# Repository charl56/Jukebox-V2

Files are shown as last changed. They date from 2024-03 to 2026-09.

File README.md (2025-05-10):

# Jukebox

This project combines **hardware** and **software** to create a connected jukebox.
It runs on a **Raspberry Pi 3B**, which hosts a web server you can access to control music playback.
The hardware part manages various components directly connected to the Pi for full jukebox functionality.

---

## Web technologies Used

* **Python**: 3.11.1
* **Node.js**: 16.17.0

---

## Run Locally

### 1. Frontend Setup

1. Navigate to the `frontend` folder:

   ```bash
   cd frontend
   ```
2. Install dependencies (only needed the first time or after adding new ones):

   ```bash
   npm install
   ```
3. Start the development server:

   ```bash
   npm run dev
   ```

---

### 2. Backend Setup

1. Navigate to the `backend` folder:

   ```bash
   cd backend
   ```
2. Install Python dependencies:

   ```bash
   pip install -r requirements.txt
   ```
3. Run the app:

   ```bash
   python app.py
   ```

* **Access the app at**: [http://127.0.0.1:8080](http://127.0.0.1:8080)

---

## Raspberry Pi Setup

Full instructions are available here:
📄 [Step-by-step guide](./raspberry/README.MD)

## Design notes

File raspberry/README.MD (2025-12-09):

# Raspberry Pi Documentation

This guide is based for a **Raspberry Pi 3B**.

## 1. Software Setup

Start with the software setup:
📄 [Step-by-step guide](./0_software/0_initialisation_raspberry.md)

---

## 2. Hardware Setup

Then follow the hardware installation steps:
📄 [Step-by-step guide](./1_hardware/0_components_position.md)

---

## 3. Useful Commands

If needed, here’s a list of useful commands:
📄 [Command reference](./commands.md)

---

pipeline, 3 jobs :  deploy and build for private and public image of project
    Public is for deploy app on server, for testing
    Private is for Raspberry application

Create `raspberry` branch, to start build and deploy public image for raspberry

Prévoir copier le répertoire git pour récupérer les fichier dans le dossier Raspberry ???

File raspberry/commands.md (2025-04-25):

## Useful commands

```bash
poweroff    # Properly shut down the Raspberry Pi

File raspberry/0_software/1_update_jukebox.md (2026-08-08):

# How to Update the Application

1. **Edit Wi-Fi Settings**
   Open the file `/etc/wpa_supplicant/wpa_supplicant.conf` and update the `ssid` and `psk` with your Wi-Fi credentials.

2. **Switch to Client Mode**
   Run the following command to switch to Wi-Fi client mode:

   ```bash
   sudo ./wifi-ap-switch.sh client
   ```

   Wait a few moments for the Raspberry Pi to connect to the network.

3. **Check Connection**
   Verify the connection with:

   ```bash
   ping ostudio426.com
   ```

4. **Pull the Latest Jukebox Version**
   Run the update script:

   ```bash
   ./pull-jukebox.sh
   ```

   > If an error occurs, simply run the command again.

5. **Reboot the Raspberry Pi**

   ```bash
   sudo reboot
   ```

6. **Start new version**
   Run the start script: 
   ```
   ./start-jukebox.sh
   ```

Then, go to [http://raspberrypi.local](http://raspberrypi.local)
---

## Additional Info

* ⚠️ Sometimes this command may not work properly. In that case, it's better to reboot:

  ```bash
  sudo reboot
  ```

  > The Raspberry Pi will start in AP mode by default.

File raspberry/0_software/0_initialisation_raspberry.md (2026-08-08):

# Raspberry Pi – USB Key Setup (Raspberry Pi OS Lite 64-bit)

## Boot from USB Key with Raspberry Pi OS Lite (64-bit)

Start by install the OS using the image in the `XXX` folder on your SD card.

> The image includes:
>
> * Docker pre-installed
> * Access Point (AP) and Client mode setup
> * Scripts to pull and run the latest Docker image

* **Username:** `user`
* **Password:** `network!`

Une fois connecté vous avez accès à différents script .sh, et également à des fichiers .py pour tester manuellement les composants

🟢 On first boot, the Raspberry starts in Access Point (AP) mode.
You can directly access the Jukebox application already installed.

You need to connect to wifi network `Jukebox`, with SSID : `12345678`

Then, go to [http://raspberrypi.local](http://raspberrypi.local)

---

## Doc : Update Jukebox's application

If you need to update the application:
📄 [Step-by-step guide](./1_update_jukebox.md)

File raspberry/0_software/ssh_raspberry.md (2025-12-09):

# Connexion à la Raspberry Pi et lancement de l'appli

## Première connexion

1. Brancher la carte SD à l'ordinateur.
2. Modifier le fichier `root/cmdline.txt`.
3. Ajouter à la fin du fichier : `ip=169.254.25.25`

## Connexion SSH

1. Brancher la Raspberry Pi au PC via un câble Ethernet.
2. Exécuter la commande SSH suivante :
```bash
ssh -L 5025:127.0.0.1:5025 charl@169.254.25.25
```
3. Mot de passe : `network!`

## Création d'un tunnel avec MobaXterm

1. Ouvrir MobaXterm.
2. Accéder au menu : `Tunneling`.
3. Configurer les options suivantes :

   - **Forwarded port** : `5025`

   * SSH Server :
     - **Adresse** : `169.254.25.25`
     - **User** : `charl`
     - **Port** : `22`

   * Remote Server :
     - **Adresse** : `127.0.0.1`
     - **Port** : `5025`

---
Avec ce setup, vous recevrez le port 5025 de la Raspberry Pi sur votre PC.

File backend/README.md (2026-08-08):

Des fichiers de tests sont sur la raspbrery
pour les lancer : sudo python ...

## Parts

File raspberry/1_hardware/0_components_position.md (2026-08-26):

Pins are setup in 📄 [config file](../../backend/embedded/config.py)

Raspberry PI 3B Model V1.2, pin out
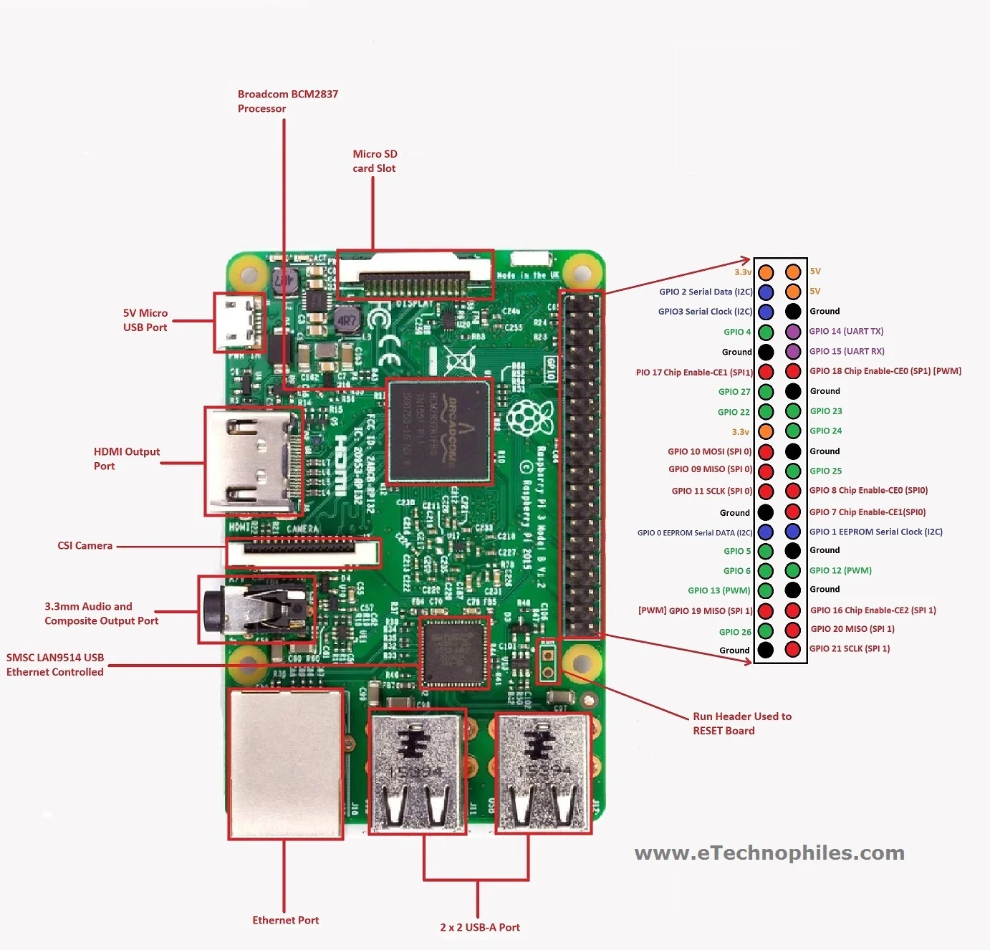
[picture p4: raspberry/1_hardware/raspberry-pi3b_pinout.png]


From : https://www.etechnophiles.com/raspberry-pi-3-gpio-pinout-pin-diagram-and-specs-in-detail-model-b/

Mon fin de course en SWITCH3 étant cassé, je l'utilise à l'envers. Fonction utilisé pour inverser sa valeur 
getRealValueOfSwitch3 dans utils.py

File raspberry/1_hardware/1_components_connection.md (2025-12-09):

Ici, decrire avec des photos/schemas comment brancher les différents composants : moteurs, capteurs, lecteur...

	Contrôler 2 moteurs pas à pas pour déplacement X et Y
		Avec des ponts en H
	Contrôler 1 servo moteur pour déplacement Z
	Contrôler l'activation de l'electro aimant
	Contrôler 4 capteur de fin de course
	Contrôler 3 GPIO en plus : contrôler le lecteur cd
		Play, pause, et pour le capteur qui détecte si le couvercle du lecteur est fermé
	Puissance de processeur/ram pour faire tourner un serveur web, et y accéder en wifi

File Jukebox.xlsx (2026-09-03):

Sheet: Reprise
Jukebox : se poser avec feuille et réfléchir sur le lecteur, prévoir taff dans les prochains jours, dessin du rendu final, s'aider de ce qui existe
Détailler chaques étapes et ordre avant de commencer
 |  | Filmer les anvancées avec les pièces 3D
Tâches | Détail | Avancée | Etapes Construction |  | Etapes Modé 3D |  | Etapes programmation |  | Pièces 3D
Ranger le bureau pour avoir de l'espace pour taffer
Relancer pour voir ce que ça donne
 |  |  | Etapes | Status | Pièce | Status | Etapes | Status | Status | Pièce globale | Pièce 3D | Précision | Dimensions2 | Colonne5 | Colonne1
Mouvements structure |  | 89.00% | Tester accroche CD | Ok | A chaque fois tester les dimensions avant les pièces entières |  | Déplacement X Y manuel | Ok | STL Prêt | Prise CD | Pièce dos cd avec aimant
Trouver 2 capteurs fin de course |  | 100.00% | Tester prise CD avec electro aimant | Ok | Fixer elecamant sur déplacement Z | Ok | Déplacement Z manuel | Ok |  |  |  | Largeur tube dans cd | 1,48cm pour une largeur de 1,5cm
Placements : | - En bas, s'aider de la plaque pour bloquer la descente, sur la droite - En haut, coller le capteur plus bas, sur le raill. - A droite, OK -A gauche, fixer comme droite | 100.00% | Tester déplacement elec aimant Z | Ok | Fixer déplacementZ sur armature imprimante | Pièce OK mais tester deplacement. REFAIRE ?? | Contrôle électro aimant | Ok |  |  |  | Largeur tige qui va dans le plateau du lecteur | 0,57cm pour une largeur de 0,6cm
On mets au max, la positon des cds se fera via config manuelle | Utiliser de la colle ? FAIRE des rallonges | 100.00% | Tester déplacement X et Y | Nickel ! | Pièce sur CD | Ok |  |  |  |  |  | Chanfrein pour épouser la forme du plateau | 1,8cm pour une largent de 1,8cm
Récupérer le signal de la raspberry sur le container docker |  | 100.00%
Regarder lesquels sont branchés où dans le code |  | 100.00% | Installer lecteur CD |  | Support cd avec plaque metal, faire un bout qui depasse, pour centrer le cd | Ok | Lien Docker Pins | Ok |  |  | Pièce face cd avec rondelle
Vérifier potentiomètres moteurs, calcul à la main !! Sans IA au début, puis on vérifie Pb : Moteur X fait du bruit quand branché, CHAAUUFFFEEE | A4988 -> Je ne trouve pas RSens, donc galère de calculer Vref Si pas trop de bruits ~ Okk | 0.00% | Plaque avec support Cds et lecteur, prévoir place lecteur ! | Ok
Vérifier le code pour pour tester manuellement - Fonction moveX/Y, ajouter le recul si capteur detecté |  | 100.00% | Ralonge câbles | Ok | Modéliser rendu final, pour voir où placer quoi | Ok | Pb lecteur, le changer ?? | A faire
Teste manuel déplacement : # Detection des capteurs avec retour marge OK # Fonction moveTo/origin/end OK # Init machine a etats puis attente actions OK # Calibrer les positions OK # playCd -> Bouge au CD puis reviens origin OK // Pb : timeout de 10s, si mouvement plus long la connexion coupe https://claude.ai/chat/1f9255f3-cb82-455e-8c4a-e6fc560f6c47 MIS EN PLACE 30s : TESTER |  | 100.00% | Prévoir tiges? pour fixer armature à planche, avec une certaine distance | Ok |  |  | PREVOIR DES DETECTEURS DE FIN DE COURSE | A faire
# Déplacement Z GOOD MAIS Il faut 3 plaques plutot que des rond en alu pour aimanter les cd sur la face |  | 90.00% |  |  | IMPRIMER PIECES | Ok | Construire stucture | A faire | Prêt, j'ai déjà la pièce | Support pose cd sur mur |  |  |  |  |  | Font
Ajouter le lecteur sur le front avec cd qui tourne + borderau en quand on ferme le lecteur - Voir dessin |  | 100.00% |  |  |  |  | Calculer nb step pour chaque positions | A faire |  |  | Utiliser les plateaux de lecteurs aimantés |  |  |  |  | Tous les cd se refresh quand on dragNdrop
BIEN PLACER STEP MOTEUR POUR STEP 0 TOUT EN HAUT (ORIGINE) |  |  | Construire machine | Ok |  |  | Code général : machine à état | Une fois que tout fonctionne manuellement
MoveX(Dir,Step), on break si on touche un mur, on renvoi quoi dcp ? Ces données ? Non j'imagine, mais dcp on renvoi les qqlq pas du retour ?
Lecteur CD |  | 0.00% |  |  |  |  |  |  | AliExpress | Déplacement elec aimant
Nouveau lecteur à trouver | Trouver ouverture par le dessus, avec une tige de lecteur assez grande | 0.00% |  |  |  |  |  |  |  |  |  |  |  |  |  | Créer image déjà prête, sans imager toute la carte SD. MàJ doc raspberry/0_software/0_initialisation_raspberry.md
 | Avec 4 fixation comme celui actuel | 0.00% |  |  |  |  |  |  |  |  |  |  |  |  |  | "... the image in XXX filder ..."
Tester lecture CD |  | 0.00%
Changer le support | Partie délicate | 0.00%
Sortir le lecteur, check les branchements | J'espère j'ai les mêmes | 0.00%
Remplacer sur la jukebox |  | 0.00% |  |  |  |  | CR2ER IMAGE DE LA CARTE SD DE LA RASPBERRY
 |  |  |  |  |  |  | V2RIFIER README
Machine à états |  | 75.00%
Wait | Attente d'instructions | 100.00%
MoveCdFromTo (X/Y, Z, aimant, Z, X/Y, Z, aimant, Z) | Déplace un CD d'une position à une autre | 100.00%
GoToOrigin | Va à l'origine jusqu'à déclencher les pas à pas | 100.00%
Play/pause/stop | Pour ces actions, liste d'attente ? Ou alors on accepte une nouvelle opération dès que celle en cours est terminée | 0.00%
PCB avec raspberry, driver moteurs, alims...
1 alim pour moteurs, raspberry, lecteur
fichier update_jukebox : faire tous les scritp en 1 ?
Dernière vérif avec multimetre pour valider les moteurs PàP
Déplacement en Z elecAimant
Réimprimer ?? Trouver une imprimante
Application, afficher les CD enregistés : fomarter la hauteur de l'image et largeur pareil pour tout. Ex : ADC et PBB
Image du projet sur la Raspberry
Vidéo présentation
Camera film machine et ecran, l'un a cote de l'autre, les enceintes de chaque côté de la jukebox
On démarre, on va sur le site
On lance un premier CD
Play/pause/volume/suivant...
On change le CD ,on le lance
AJouter/modifier/supprimer dans les CD enregistrés
On change des CDs sur l'interface
On changer également un cd de la jukebox, changement support
Lancement nouveau CD

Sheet: Matos
Moteur 17HS15-0404S | Pilote A4988
Raspberry PI 3B

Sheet: Archive - Setup Raspberry
 |  | Steps | command
 |  | Setup raspOs lite | Raspberry Pi imager
 |  | Install pip3 | apt install python3-pip
 |  | Copy files backend | Branchez votre clé USB sur votre ordinateur.
 |  |  | Ouvrez un terminal.
 |  |  | Identifiez le nom de périphérique de votre clé USB. Vous pouvez le faire en utilisant la commande lsblk. Par exemple, votre clé USB pourrait être identifiée comme /dev/sdb.
 |  |  | Montez la clé USB. Si elle n'est pas déjà montée automatiquement, vous pouvez le faire en utilisant la commande sudo mount /dev/sdX /mnt, où /dev/sdX est le nom de périphérique de votre clé USB.
Se connecter en wifi : sudo raspi-config, system option, WLAN |  |  | Accédez au répertoire où vous souhaitez copier les fichiers. Par exemple, cd /home/charl/jukebox.
Installer docker | 1. Assure-toi que ton système est à jour : |  | Copiez les fichiers de la clé USB vers ce répertoire en utilisant la commande sudo cp -r /mnt/* . Cette commande copiera tous les fichiers et dossiers de la clé USB vers le dossier /home/charl/jukebox.
 | sudo apt update && sudo apt upgrade -y |  | Une fois la copie terminée, vous pouvez démonter la clé USB en utilisant la commande sudo umount /mnt.
 | 2. Installe les dépendances : |  | Débranchez votre clé USB en toute sécurité.
 | sudo apt install -y ca-certificates curl gnupg lsb-release | Install requirements | pip3 install -r requirements
 | 3. Ajoute la clé GPG officielle de Docker : | Test exec python app | python3 app.py
 | sudo mkdir -p /etc/apt/keyrings | Create systemctl file | nano /etc/systemd/system/jukebox.service
 | curl -fsSL https://download.docker.com/linux/debian/gpg | sudo gpg --dearmor -o /etc/apt/keyrings/docker.gpg | (permet de démarrer l'app au lancement de la rasp) | [Unit]
 | 4. Ajoute le dépôt Docker compatible ARM : |  | Description=Flask App
 | echo \ |  | After=network.target
 | "deb [arch=armhf signed-by=/etc/apt/keyrings/docker.gpg] https://download.docker.com/linux/debian \ |  | [Service]
 | $(lsb_release -cs) stable" | \ |  | User=root
 | sudo tee /etc/apt/sources.list.d/docker.list > /dev/null |  | Group=root
 | 5. Met à jour les paquets avec le nouveau dépôt : |  | WorkingDirectory=/home/charl/jukebox/backend
 | sudo apt update |  | ExecStart=/usr/bin/python3 /home/charl/jukebox/backend/app.py
 | 6. Installe Docker Engine : |  | Restart=always
 | sudo apt install -y docker-ce docker-ce-cli containerd.io docker-buildx-plugin docker-compose-plugin |  | [Install]
 |  |  | WantedBy=multi-user.target
 |  |  | sudo systemctl daemon-reload
 |  |  | sudo systemctl start jukebox
 |  |  | sudo systemctl status jukebox
 |  |  | sudo systemctl enable jukebox
 |  | SSH connection with access to python app, ethernet | ssh -L 5025:127.0.0.1:5025 charl@169.254.76.59, si pb voir ssh_raspberry.md

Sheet: Archive - Mache à état
Variables | Explocation | Init | GoToOrigin | Wait | NewAction | GoToPos | Play | Pause | Stop
maxStepX | Int, nb de step pour aller d'un côté à l'autre | MoveX(, "cw") jusqu'à la limite (interrupteur se déclenche) | Permet de replacer la jukebox en bas a gauche | Attente d'un action | On récupère l'action voulu : placer un cd, enlever, wait | On se déplace en X et Y aux coordonnées coordGoTo | Change actualPlayerAction a play | Change actualPlayerAction a pause | Change actualPlayerAction a stop
maxStepY | Int, nb de step pour aller d'un côté à l'autre | Préparer une variable maxStepX, à 0 |  | While nextStep null | Si wait | On avance en Z pour se rapprocher du lecteur |  |  | On range le cd actuel a sa position
 |  | MoveX(, "ccw") jusqu'à la limite (interrupteur se déclenche), et incrémente maxStepX |  |  | Prochain état : wait | on active l'electroaimant
nextCd | Int, contient l'id du cCD qu'on souhaite positionner | Sauvegarder le nombre de step pour aller de droite à gauche |  |  |  | on recule en Z
previousCd | Int, contient l'id du CD si il y en a un sur le player (de 1 à 9, sauf 5 le lecteur) |  |  |  | Si enlever | On se déplace en X et Y aux coordonnées coordGoToAfter
coordGoTo | Coordonnées ou doit se déplacer l'electroaimant | MoveY(, "cw") jusqu'à la limite (interrupteur se déclenche) |  |  | GoToPos = 5 (position du lecteur) | On avance en Z pour se rapprocher de la position
coordGoToAfter | Coordonnées ou doit se rendre l'elecroaimant ensuite (avant coordonnées ou prendre un cd, la ou poser) | Préparer une variable maxStepY, à 0 |  |  | GoToPosAfter = previousCd ( l'id du dernier cd poser sur le lecteur) | On desactive l'electroaimant
locationsPos | JSON, contient les 9 position possible (dont 5 pos du lecteur), avec nb de step pour aller a chaque, en partant de l'origin | MoveY(, "ccw") jusqu'à la limite (interrupteur se déclenche), et incrémente maxStepY |  |  | Prochain état : GoToPos
 |  | Sauvegarder le nombre de step pour aller de bas en haut
playerActions | Liste des différentes action : play, pause, stop
actualPlayerAction | valeur stop de base |  |  |  | Si placer
 |  |  |  |  | Si la var previousCd est diffférente de 0, alors un CD est sur le lecteur
nextState |  |  |  |  | GoToPos = previousCd, normalement init a l'ajout d'un cd
 |  | Prochaine état : GoToOrigin | Prochain état : Wait |  | GoToPosAfter = position du lecteur | Prochain etat : NewAction(wait) | Prochain etat : wait | Prochain etat : wait
 |  |  |  |  | previousCd = 0
 |  |  |  |  | Prochain état : GoToPos
 |  |  |  |  | Si la var previousCD == 0
 |  |  |  |  | previousCd = nouvelle valeur
 |  |  |  |  | nextCd est la position du lecteur
 |  |  |  |  | GoToPos = position previousCD
 |  |  |  |  | GoToPosAfter = position du lecteur
 |  | Setup positions manuellement des coordonnées | Départ à l'origin | CD en place ?
 |  | Utiisation du clavier, 4 flèches de direction | Déplacement en XY | Si oui va au lecteur
 |  | Déplacement de l'aimant jusqu'en face des cds | Approche ventouse | Récupère en mémoire la position du cd, et le dépose la bas
 |  | Compter le nb de step pour aller à un emplacement | Ventouse ON | Fin si
 |  | Sauvegarder cette valeur dans un json ? | Recule ventouse | Récupérer le cd voulu, à sa position
 |  |  | Déplacement en XY | Va sur le lecteur, pose le cd
 |  |  | Approche ventouse | Sauvegarde la position du cd sur le lecteur
 |  |  | Ventouse OFF
 |  |  | Recule ventouse
 |  |  | Déplamcenet origin

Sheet: Archive - Cahier des charges
 | Partie App | Priorité
 | Page d'accueil, qui affiche les CDs dispos | 1
 | Fichier JSON pour stocker les données, comme il n'y en a pas bcp | 1
 | Attributs CD : nom album, artiste, photo phochette, nombre de tracks, année sortie, position jukebox (numéro de 1 à 9, avec lecteur cd = 5) | 1
 | Boutons pour ajouter/modifier/supprimer CD | 1
 | Bouton Play/Pause/Stop | 1
 | Play : Lance le cd (ajoute le cd sur le lecteur, et lance le lecteur) | 1
 | Pause : Stop le cd (pause sur le lecteur) | 1
 | Stop : Enlève le cd du lecteur (remet le cd à sa place) | 1
 | Afficher un lecteur cd sur l'app | 2
 | CD tourne si Play | 2
 | CD tourne pas si Pause | 2
 | Rien si Stop | 2
 | Même mise en forme que la jukebox, avec lecteur cd au milieu et CDs autour | 2
 | Possibilité de changer de place un CD | 2
US | Partie Raspberry | Priorité | Colonne1
1 | Structure général
1.1 | Les moteurs sont contrôlés par la Raspberry, via les actions sur l'application
1.2 | Il y a un total de 9 places, dont la 5 qui est pour le lecteur cd
1.3 | Le code doit gérer les états des cd, pour par exemple remettre le cd en cours à sa place, si un nouveau est choisit
1.4 | Interrupteur général pour tout éteindre
1.5 | Créer la structure général, trouver les matériaux adaptés
1.6 | Avant tout, être sur du fonctionnement, moteurs pas à pas, nacelle…
2 | Accès application
2.1 | Raspberry en mode AP : on s'y connect en wifi et on peut accéder à l'appli pour gérer la jukebox
3 | Déplacement en Y
3.1 | 2 moteurs pas à pas avec des tiges filetées |  | Les 2 moteurs chauffent, aller à l'école pour réglage potentiomètre : https://lebearcnc.com/reglage-des-drivers-pour-moteurs-pas-pas-pololu-a4988-drv8825-drv8824-et-drv4834/
3.2 | Il faut donc une genre de nacelle qui relire les 2 tige filetées, qui va monter/descendre en fonction des moteurs
3.3 | Il faut donc aussi trouver le bon rapport entre la vitesse du moteur, et les pas de la tige filetée pour ne pas être trop lent, mais quand même précis
3.4 | Et faire en sorte que la nacelle ne soit pas trop lourde pour les moteurs
3.5 | Il y a un roulement à bille en haut pour sabiliser les tiges filetées et les tenir bien droite
4 | Déplacement en X
4.1 | 1 moteur pas à pas pour déplacement électroaimant en X, via une tige filetée
4.2 | Le moteur est sur la nacelle, et à une deuxième nacelle sur sa tige filetée, qui se déplace de droite à gauche en fonction du moteur
4.3 | Pareil, trouver un bon rapport entre vitesse et pas de la tige filetée, mais ça sera surement le même
4.4 | Pareil, roulement à bille au bout
5 | Déplacement en Z
5.1 | Sur la nacelle : 1 servo moteur pour déplacement électroaimant en Z
5.2 | Besoin de quelques pièces 3D pour le mouvement |  | https://www.youtube.com/watch?v=2vAoOYF3m8U
5.3 | L'électroaimant doit être au bout, afin de se rapprocher/éloigner des cd
5.4 | Prévoir un fil suffisament long pour le contrôle de l'électroaimant
6 | Electroaimant
6.1 | Il permet donc de prendre les cd et de les placer sur leur socle ou sur le lecteur cd
6.2 | Mettre un aimant sur le cd, en forme de rond autour du trou
6.3 | Mettre un aimant sur le socle du cd, pour qu'il soit un minimum tenu
6.4 | Mettre un aimant puissant sur le lecteur pour tenir le cd
6.5 | 3 niveaux de puissance des aimants : Electroaimant>lecteur>socle
7 | Socle cd
7.1 | Pièces imprimée en 3D je pense, qui se colle sur la plaque. Ils ont un aimant afin de maintenir un minimum le cd
8 | Interrupteur fin de course
8.1 | Afin de détecter quand la nacelle arrive à une extrémité (haut,bas,droite,gauche)
9 | Lecteur CD
9.1 | Trouver un lecteur cd
9.2 | Réussir à récupérer le son, en utilisant un système le plus simple possibe
9.3 | Ex : Récupérer un lecteur entier, et le mettre sur le mur, même si je dois appuyer sur play pour l'instant
10 | Sortie du son
10.1 | Le son sort d'un cable jack, ce qui permet de brancher sur des enceintes, casque…
10.2 | Pourquoi pas module bluetooth par la suite
11 | Calibration des moteurs pas à pas
11.1 | Au démarrage, faire en sorte que la nacelle va tout en bas à gauche, puis tout en haut a droite
11.2 | Comme ça on récupère le nombre de pas pour faire la hauteur et la largeur, et on calcul la position des cd grâce à ça

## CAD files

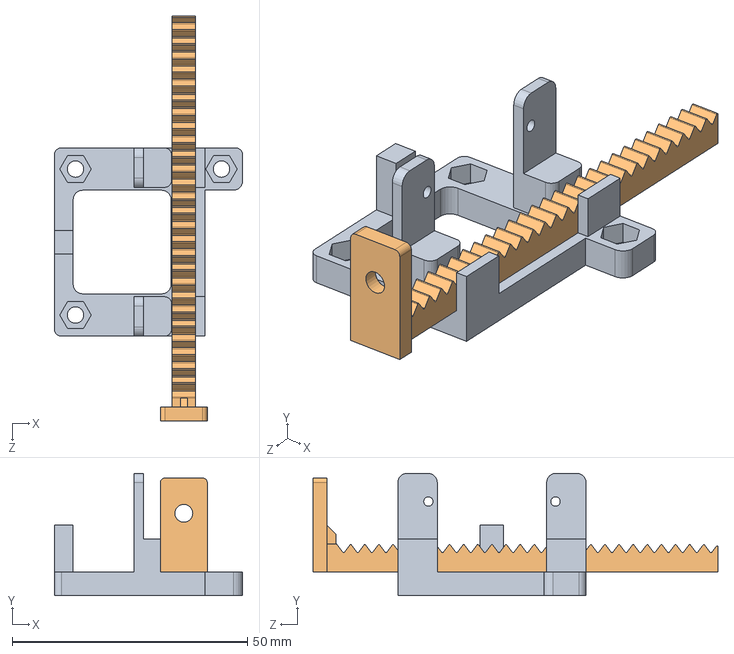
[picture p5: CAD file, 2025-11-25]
models/V3/Assemblage_elecaimant.SLDASM
40.0 x 26.0 x 86.0 mm
Raille_eleaimant
Support_elecaimant

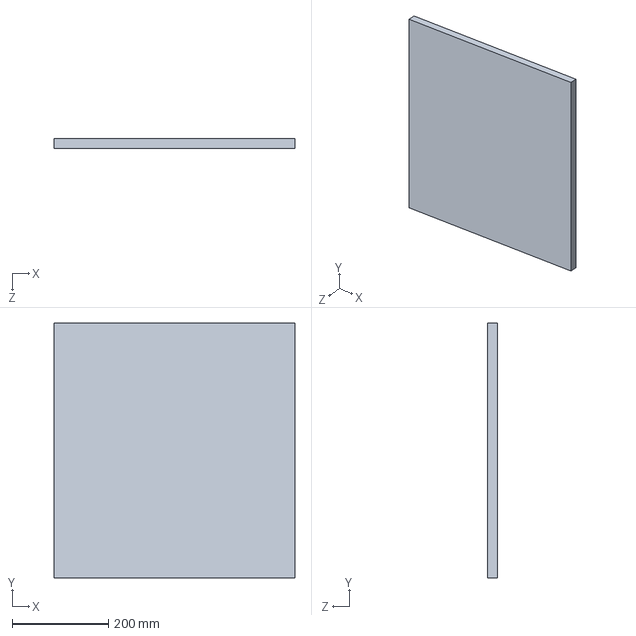
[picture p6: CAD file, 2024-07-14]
3d_models/plaque.SLDPRT
500.0 x 530.0 x 20.0 mm

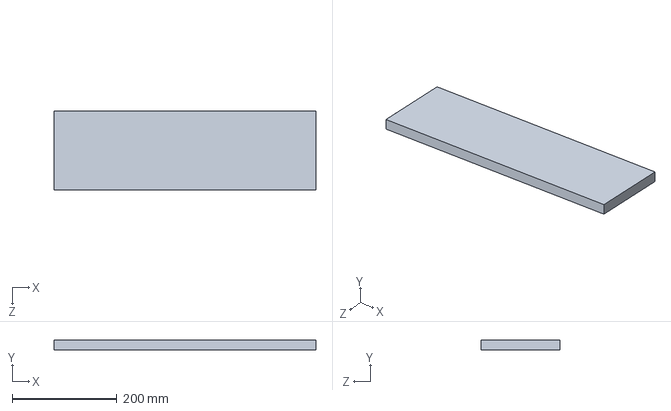
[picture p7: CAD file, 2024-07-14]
3d_models/socle.SLDPRT
500.0 x 20.0 x 150.0 mm

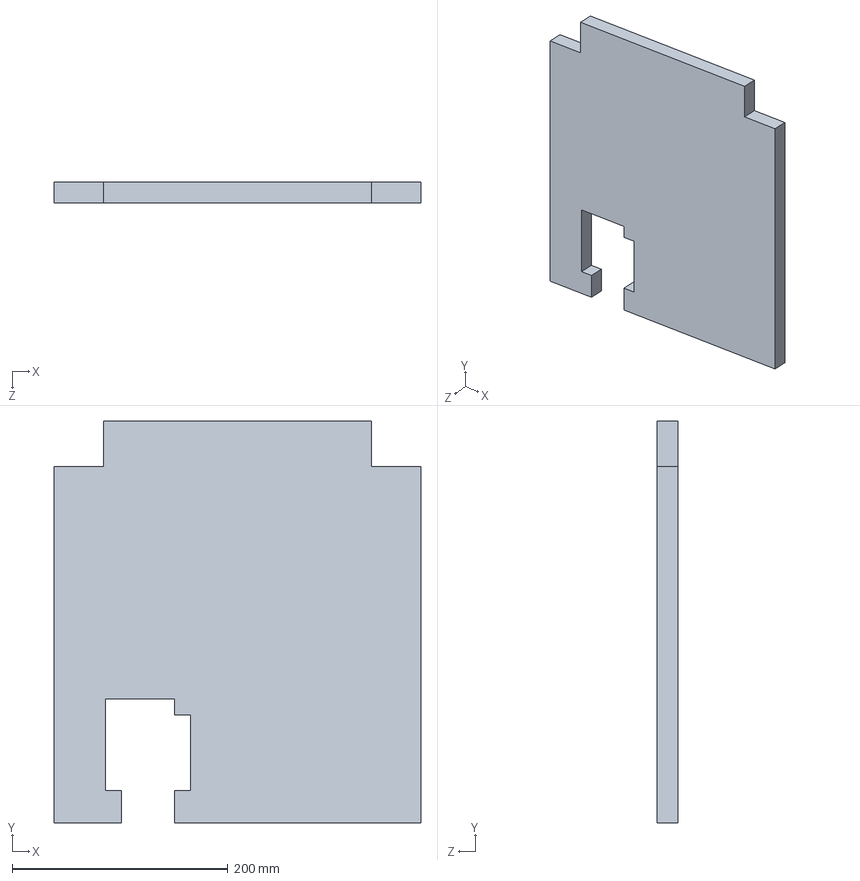
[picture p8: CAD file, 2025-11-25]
models/V3/plaque.SLDPRT
340.0 x 372.5 x 19.0 mm

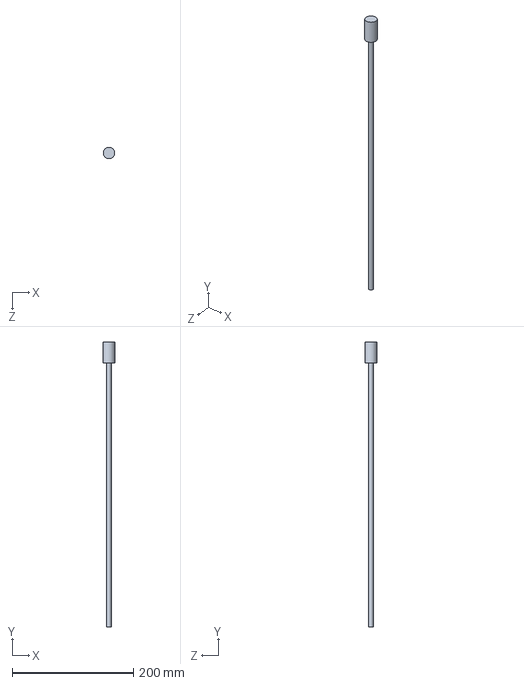
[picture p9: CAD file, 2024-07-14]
3d_models/tige_filetee.SLDPRT
19.0 x 470.0 x 19.0 mm

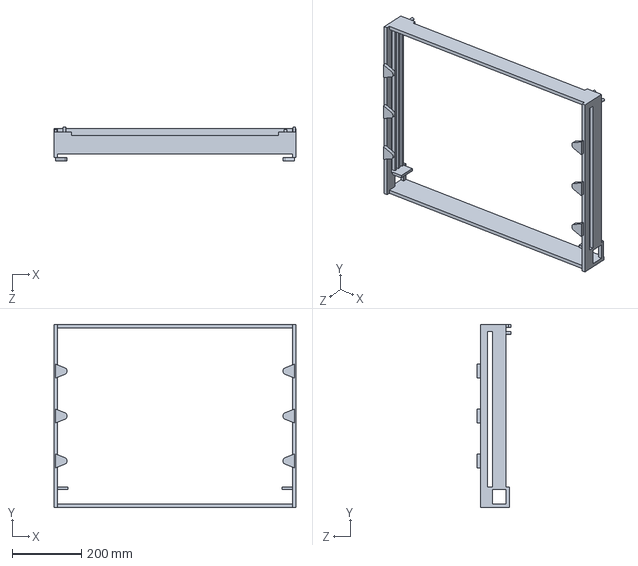
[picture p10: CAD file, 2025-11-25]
models/socle2.SLDPRT
700.0 x 530.0 x 99.0 mm

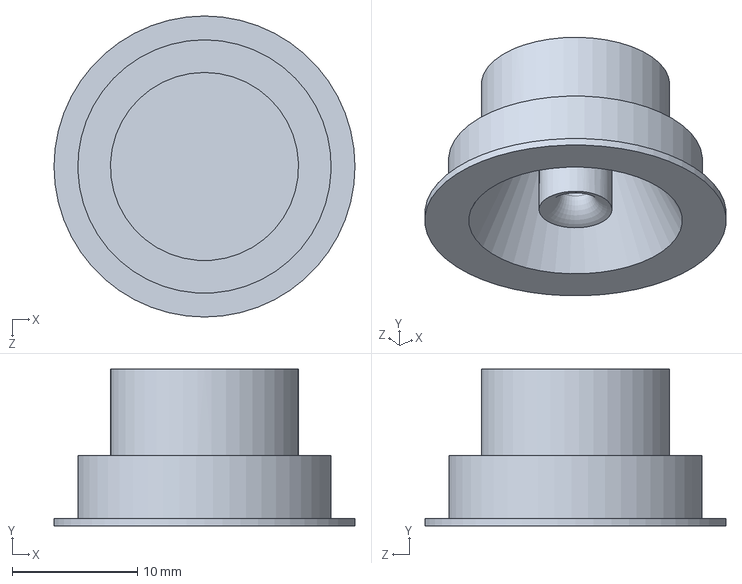
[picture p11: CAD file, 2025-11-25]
models/V3/Support_cd_dos_aiamant_devant.SLDPRT
24.0 x 12.5 x 24.0 mm

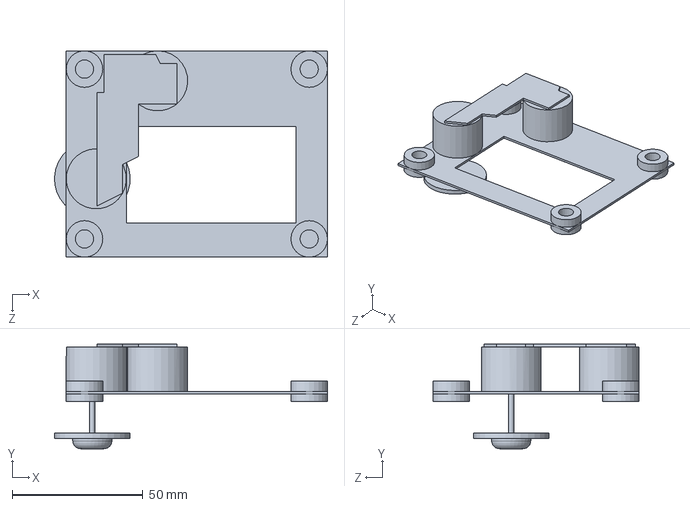
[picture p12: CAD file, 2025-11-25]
models/lecteur_cd_v2.SLDPRT
104.5 x 40.0 x 79.0 mm

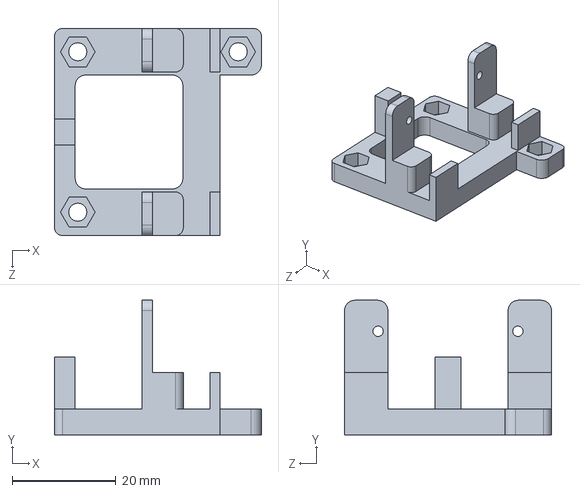
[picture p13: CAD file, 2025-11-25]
models/V3/Support_elecaimant.SLDPRT
40.0 x 26.0 x 40.0 mm

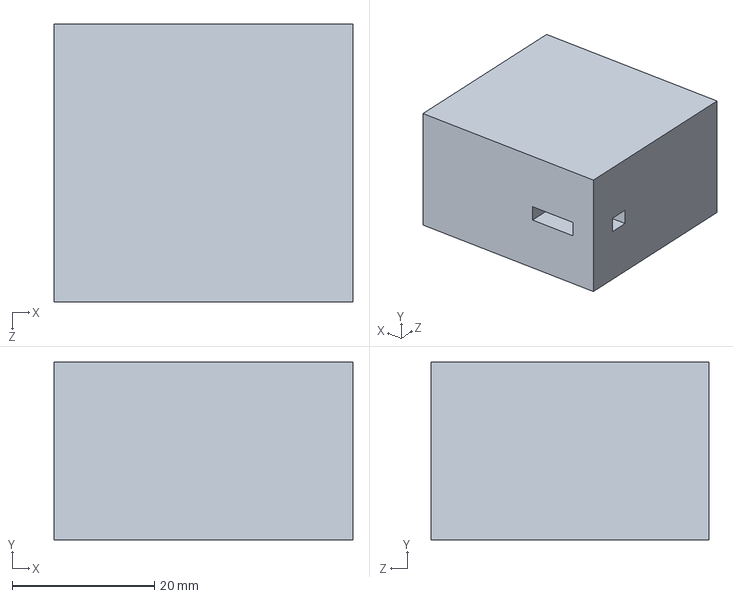
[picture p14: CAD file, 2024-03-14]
3d_models/support_tige_depl_x.SLDPRT
42.0 x 25.0 x 39.0 mm

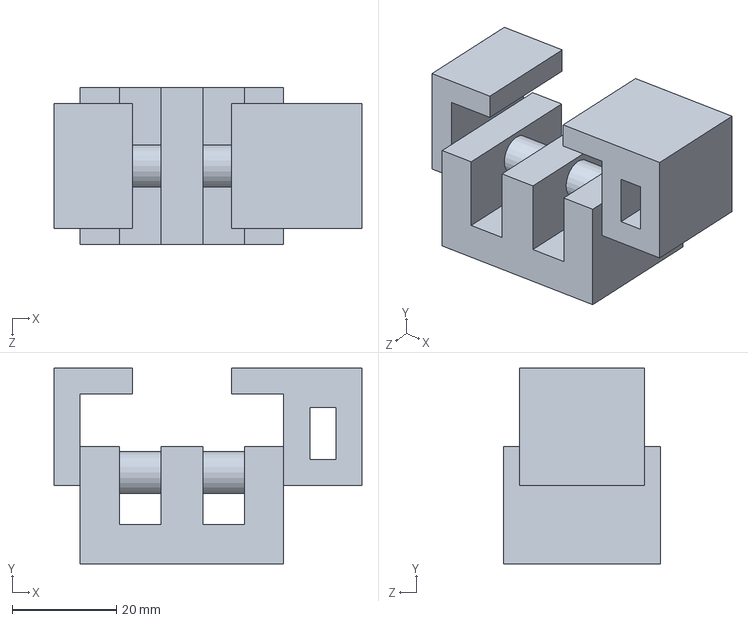
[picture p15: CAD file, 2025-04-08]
models/support_nacelle.SLDPRT
59.0 x 37.5 x 30.0 mm

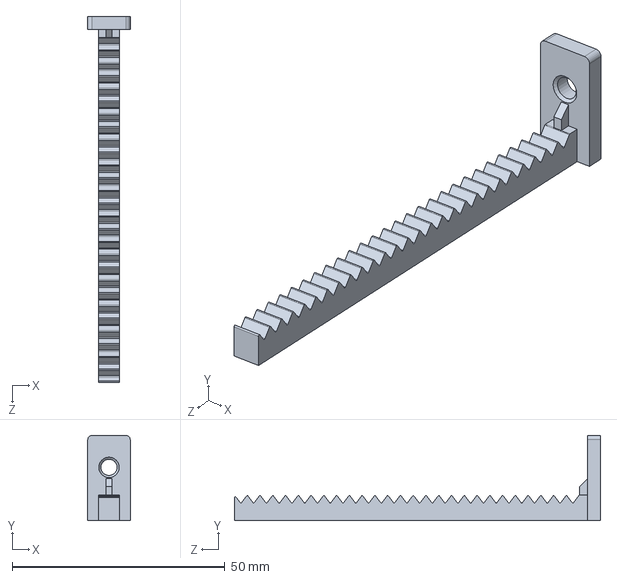
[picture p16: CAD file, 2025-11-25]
models/V3/Raille_eleaimant.SLDPRT
10.0 x 20.0 x 86.0 mm

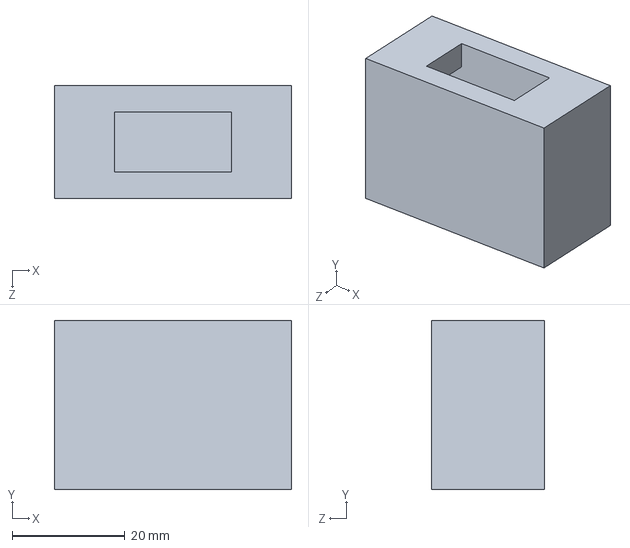
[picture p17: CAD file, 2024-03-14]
3d_models/fin_de_course_haut.SLDPRT
42.0 x 30.0 x 20.0 mm

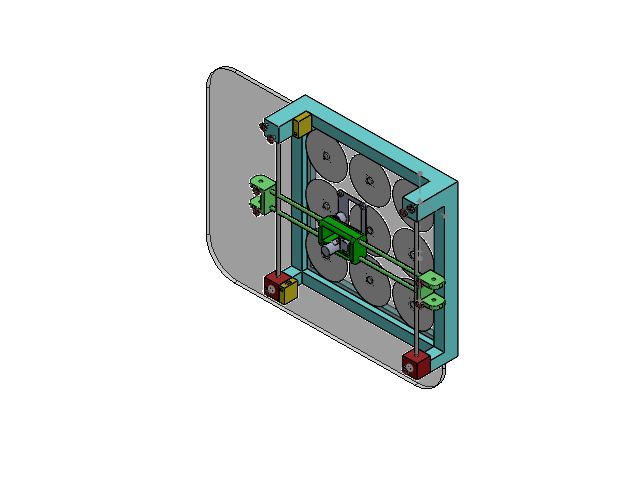
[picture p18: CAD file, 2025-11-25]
models/assemblage_plexi.SLDASM
plaque_plexi
servo_moteur x 2
plateau_moteur_lecteur x 9
roulement_billes x 9
cd x 9
cadre_plexi
lecteur_cd_v3_avec_support
pinion_gear_mini x 11
tige_filetee_petite x 2
support_nacelle_v2_courroies
fin_de_course_basGrand x 2
nacelle_v2
servo_fs90r

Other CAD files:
models/V3/Assemblage_cd.SLDASM
models/Assemblage2.SLDASM
3d_models/Assemblage.SLDASM
models/V3/Assemblage_final.SLDASM
3d_models/cd.SLDPRT
3d_models/depl_x.SLDPRT
3d_models/depl_x_gauche.SLDPRT
3d_models/ecrou_nacelle.SLDPRT
3d_models/electroaimant.SLDPRT
3d_models/fin_de_course_bas.SLDPRT
3d_models/lecteur_cd.SLDPRT
3d_models/motor bracket, mini version.SLDPRT
3d_models/motor_bracket_mini.SLDPRT
3d_models/motor_bracket_mini_2.SLDPRT
3d_models/nacelle_grande_bas.SLDPRT
3d_models/nacelle_grande_haut.SLDPRT
3d_models/nacelle_petite.SLDPRT
3d_models/pinion_gear_mini.SLDPRT
3d_models/pusher_100mm_long.SLDPRT
3d_models/pusher_125mm.SLDPRT
3d_models/roulement_billes.SLDPRT
3d_models/servo_fs90r.SLDPRT
3d_models/servo_moteur.SLDPRT
3d_models/support_cd.SLDPRT
3d_models/support_roulements.SLDPRT
3d_models/tige_depl_x.SLDPRT
3d_models/tige_filetee_petite.SLDPRT
models/Assemblage - Copie.SLDASM
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

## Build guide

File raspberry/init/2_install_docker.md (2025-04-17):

### ✅ Étapes pour installer Docker sur Raspberry Pi (3B) :

1. **Assure-toi que ton système est à jour :**

```bash
sudo apt update && sudo apt upgrade -y
```

2. **Installe les dépendances :**

```bash
sudo apt install -y ca-certificates curl gnupg lsb-release
```

3. **Ajoute la clé GPG officielle de Docker :**

```bash
sudo mkdir -p /etc/apt/keyrings
curl -fsSL https://download.docker.com/linux/debian/gpg | sudo gpg --dearmor -o /etc/apt/keyrings/docker.gpg
```

4. **Ajoute le dépôt Docker compatible ARM :**

```bash
echo \
  "deb [arch=armhf signed-by=/etc/apt/keyrings/docker.gpg] https://download.docker.com/linux/debian \
  $(lsb_release -cs) stable" | \
  sudo tee /etc/apt/sources.list.d/docker.list > /dev/null
```

5. **Met à jour les paquets avec le nouveau dépôt :**

```bash
sudo apt update
```

6. **Installe Docker Engine :**

```bash
sudo apt install -y docker-ce docker-ce-cli containerd.io docker-buildx-plugin docker-compose-plugin
```

7. **Teste Docker :**

```bash
sudo docker run hello-world
```

Tu devrais voir un message indiquant que Docker fonctionne bien 🎉

---

### 🔧 (Optionnel) Utiliser Docker sans `sudo` :

Ajoute ton utilisateur au groupe `docker` :

```bash
sudo usermod -aG docker $USER
```

Puis **redémarre ta session ou redémarre la Pi** :

```bash
sudo reboot
```

Après ça, tu pourras faire :

```bash
docker ps
```

sans avoir besoin de `sudo`.

---

Tu veux aussi Docker Compose (en ligne de commande) ou tu comptes utiliser `docker compose` directement ?

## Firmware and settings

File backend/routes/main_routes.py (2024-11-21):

# routes/main_routes.py
from flask import Blueprint, render_template, send_from_directory

main_bp = Blueprint('main', __name__)

@main_bp.route('/')
def index():
    return render_template('index.html')

@main_bp.route('/assets/<path:filename>', methods=['GET'])
def serve_static(filename):
    return send_from_directory('templates/assets', filename)

@main_bp.route('/images/<path:filename>', methods=['GET'])
def return_image(filename): 
    return send_from_directory('static/', filename)

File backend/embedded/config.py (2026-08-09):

import os

# Determine environment
IS_ON_SERVER = os.getenv("IS_ON_SERVER", "False") == "True"
IS_ON_RASPBERRY = os.getenv("IS_ON_RASPBERRY", "False") == "True"

print(f"IS_ON_SERVER: {IS_ON_SERVER} | IS_ON_RASPBERRY: {IS_ON_RASPBERRY}")


NB_POSITIONS = 4
PLAYER_POSITION = 1 # A partir de 0, de gauche a droite, haut en bas

# Pins of limit switches 
SWITCH_1 = 16
SWITCH_2 = 26
SWITCH_3 = 20
SWITCH_4 = 21

# Step motor GPIOs step pins, connected to GPIOs 14, 17, 24
L_STEP = 14     # Motor plug in X, but move Y axe
R_STEP = 17     # Motor plug in Y, move Y axe

# GPIOs direction pins, connected to GPIOs 15, 27, 23
L_DIR = 15      # Motor plug in X, but move Y axe
R_DIR = 27      # Motor plug in Y, move Y axe

# Sleep time between steps for motor speed control
SLEEP_TIME = 0.002  # Adjust this value to control speed
STEP_RETURN = 20 # Nb of step when limit

# GPIO pin for the servo motor
SERVO_MOTOR = 4

# Electro magnet GPIO pin connected to the electromagnet
ELECTRO_MAGNET = 18

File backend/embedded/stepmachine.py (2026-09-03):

#!/usr/bin/python3
import threading
from time import sleep
import os
from embedded.config import IS_ON_RASPBERRY, IS_ON_SERVER, NB_POSITIONS, PLAYER_POSITION
from utils import load_json_file, save_json_file
import shutil


if(IS_ON_RASPBERRY):
    from embedded.movestepmotor import moveX, moveXToOrigin, moveXToEnd, moveY, moveYToOrigin, moveYToEnd
    from embedded.moveservomotor import moveZToAngle, moveZToOrigin
    from embedded.electromagnet import setMagnetOn, setMagnetOff
    
    import RPi.GPIO as GPIO

    LED_PIN = 18  # Vous pouvez changer ce numéro selon votre connexion
    GPIO.setmode(GPIO.BCM)  # Utilisation de la numérotation BCM
    GPIO.setup(LED_PIN, GPIO.OUT)
    GPIO.output(LED_PIN, GPIO.LOW)  # LED éteinte au démarrage
    
    


def cleanup():
    GPIO.cleanup()
# Gestionnaire pour exécuter le nettoyage à la fermeture
import atexit
atexit.register(cleanup)


class JukeboxStateMachine:
    def __init__(self):
        self.states = ["Init", "GoToOrigin", "GoToEnd", "GoToPos", "Wait", "CalculCoords", "Close", "Play", "Pause", "Prev", "Next"]
        self.current_state = "Init"
        self.next_state = None
        self.maxStepX = 0
        self.maxStepY = 0
        self.actualStepX = 0
        self.actualStepY = 0
        self.actualStepZ = 0
        self.nextCD = None
        self.cdOnMagnet = False
        self.cdInPlayer = False
        self.actualCdId = 0
        # Movements
        self.positionFirst = None
        # Coord of each positions
        self.locationsPos = []
        for i in range(NB_POSITIONS):
            self.locationsPos.append({'id': str(i + 1), 'x': 0, 'y': 0, 'origin': 0, 'player': 0, 'cd': 0})
        # Angle of Z, with servo motor
        self.locationZ = [0, 180]
        # Player actions
        self.playerActions = ["play", "pause"]
        self.actualPlayerAction = ""
        self.stepMachineActive = True
        # Thread
        self.lock = threading.Lock()
        self.wait_time = 1
        self.should_sleep = True
        # Prefix print
        self.prefix = "StateMachine"
        # Event for state completion
        self.state_complete_event = threading.Event()

    def get_player_position(self):
        return self.locationsPos[PLAYER_POSITION]

    def get_state(self):
        with self.lock:
            return self.current_state

    def set_state(self, state):
        """Appelé depuis l'extérieur du thread transition() — acquiert le lock."""
        with self.lock:
            self._set_state_locked(state)

    def _set_state_locked(self, state):
        """Appelé depuis transition(), qui tient déjà le lock."""
        self.current_state = state
        self.state_complete_event.clear()


    def transition(self):
        while self.stepMachineActive:
            with self.lock:
                if self.current_state == "Init":
                    print(f"{self.prefix} : Initializing...")
             
                    try:

                        if not os.path.exists("./static/positions.json"):
                            shutil.copy("./static/positions_empty.json", "./static/positions.json")

                        data = load_json_file("./static/positions.json")


                        if(len(data) == NB_POSITIONS):
                            self.locationsPos = data
                        elif(len(data) < NB_POSITIONS):
                            print(f"{self.prefix} : Not enough positions in JSON. Expected {NB_POSITIONS}, got {len(data)}. Using default positions.")
                            data.extend([{'id': str(i + 1), 'x': 0, 'y': 0, 'origin': 0, 'player': 0, 'cd': 0} for i in range(len(data), NB_POSITIONS)])
                            self.locationsPos = data
                            save_json_file("./static/positions.json", self.locationsPos)
                        else:
                            raise FileNotFoundError(f"{self.prefix} : Too many positions in JSON. Expected {NB_POSITIONS}, got {len(data)}. Using default positions.")

                    except FileNotFoundError:
                        print(f"{self.prefix} : File not found, using default positions.")

                    self._set_state_locked("GoToOrigin")
                    self.next_state = "GoToEnd"

                elif self.current_state == "GoToOrigin":
                    print(f"{self.prefix} : going to origin...")
                    ## Etre sur que la fonction est terminée avant de passer à la suite
                    if(IS_ON_RASPBERRY):
                        moveXToOrigin()
                        moveYToOrigin()
                        if isinstance(self.locationsPos[PLAYER_POSITION].get('origin'), int):
                            moveZToAngle(self.locationsPos[PLAYER_POSITION]['origin'])
                        else:
                            moveZToOrigin()
                    
                        self.actualStepX = 0
                        self.actualStepY = 0
                        self.actualStepZ = 0

                    # Permet de retourner à l'origine sans passer par le GoToEnd
                    if self.next_state:
                        self._set_state_locked(self.next_state)
                        self.next_state = "Wait"
                    else:
                        self._set_state_locked("Wait")
                    print("Waiting for next command...")


                elif self.current_state == "GoToEnd":
                    print(f"{self.prefix} : going to end...")

                    if(IS_ON_RASPBERRY):
                        self.maxStepX = moveXToEnd()
                        self.maxStepY = moveYToEnd()

                    self._set_state_locked("GoToOrigin")

                elif self.current_state == "GoToPos":
                    if(self.next_state == "GoToPos"): self.next_state = "Wait"

                    print(f"{self.prefix} : Go from origin to position {self.positionFirst}")
                    
                    ## Move X and Y to the first position
                    if(IS_ON_RASPBERRY):

                        directionX = ""
                        stepsX = 0
                        directionY = ""
                        stepsY = 0

                        if self.actualStepX < self.positionFirst['x']:
                            directionX = "ccw"
                            stepsX = self.positionFirst['x'] - self.actualStepX
                        else:
                            directionX = "cw"
                            stepsX = self.actualStepX - self.positionFirst['x']

                        if self.actualStepY < self.positionFirst['y']:
                            directionY = "ccw"
                            stepsY = self.positionFirst['y'] - self.actualStepY
                        else:
                            directionY = "cw"
                            stepsY = self.actualStepY - self.positionFirst['y']
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

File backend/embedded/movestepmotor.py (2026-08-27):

from embedded.config import L_STEP, L_DIR, R_STEP, R_DIR, SLEEP_TIME, SWITCH_1, SWITCH_2, SWITCH_3, SWITCH_4, STEP_RETURN
import RPi.GPIO as GPIO
from time import sleep
from embedded.utils import getRealValueOfSwitch3

GPIO.setmode(GPIO.BCM)              # Paramétrage de la numérotation des GPIO en mode BCM
GPIO.setwarnings(False)             # Ne pas tenir comte des alertes
GPIO.setup([L_STEP, R_STEP, L_DIR, R_DIR], GPIO.OUT)  # GPIO STEP configuré en sortie
GPIO.setup([SWITCH_1, SWITCH_2, SWITCH_3, SWITCH_4], GPIO.IN, pull_up_down=GPIO.PUD_UP)	# rupteurs de fin de courses

def moveX(step, direction):
    """
    Function to move in X axe (RIGHT to LEFT), with step and direction

    Parameters:
    step (int): Number of steps to move.
    direction (str): Direction to move ("cw" for clockwise, "ccw" for counter-clockwise).

    Raises:
    ValueError: If step is not a non-negative integer or direction is not "cw" or "ccw".
    
    Example of use:
    moveZ(400, "cw") or "ccw"
    """
    
    if not isinstance(step, int) or step < 0:
        raise ValueError("Step must be a non-negative integer.")
    if direction not in ["cw", "ccw"]:
        raise ValueError('Direction must be "cw" or "ccw".')

    stepMoved = 0

    try:
        dir_state = GPIO.HIGH if direction == "cw" else GPIO.LOW
        GPIO.output([R_DIR, L_DIR], dir_state)

        for _ in range(step):
            GPIO.output([L_STEP, R_STEP], GPIO.HIGH)
            sleep(SLEEP_TIME)
            GPIO.output([L_STEP, R_STEP], GPIO.LOW)
            sleep(SLEEP_TIME)

            stepMoved += 1

            if GPIO.input(SWITCH_1) == 0 and direction == "cw":
                print("Limite de course atteinte en X (origine)")
                reculed = moveX(STEP_RETURN, "ccw")
                stepMoved -= reculed  # On decremente les pas fait dans l'autre sens, une fois le bout atteint
                break
            elif getRealValueOfSwitch3(GPIO.input(SWITCH_3)) == 0 and direction == "ccw":
                print("Limite de course atteinte en X (fin)")
                reculed = moveX(STEP_RETURN, "cw")
                stepMoved -= reculed  # On decremente les pas fait dans l'autre sens, une fois le bout atteint
                break
        
        sleep(0.1)

    except Exception as e:
        print(f"An error occurred: {e}")
    finally:
        return stepMoved


def moveXToOrigin():
    """
    Function to move in X axe to the origin of the rail
    """

    try:
        GPIO.output([R_DIR, L_DIR], GPIO.HIGH)
        print("Déplacement à l'origine en X")
        
        while GPIO.input(SWITCH_1):	
            
            GPIO.output([L_STEP, R_STEP], GPIO.HIGH)
            sleep(SLEEP_TIME)
            GPIO.output([L_STEP, R_STEP], GPIO.LOW)
            sleep(SLEEP_TIME)

        # Comme on est à l'ogine, on peut réinitialiser le compteur de pas à 0
        # Et on recule de X pas pour avoir une petite marge
        moveX(STEP_RETURN, "ccw")
        print("Arrivé à l'origine en X")
        

    except Exception as e:
        print(f"An error occurred: {e}")


def moveXToEnd():
    """
    Function to move in X axe to the end of the rail
    
    Return: Number of steps to reach the end of the rail
    """

    stepMoved = 0
    try:
        GPIO.output([R_DIR, L_DIR], GPIO.LOW)
        print("Déplacement au max en X")
        
        while getRealValueOfSwitch3(GPIO.input(SWITCH_3)):	
            
            GPIO.output([L_STEP, R_STEP], GPIO.HIGH)
            sleep(SLEEP_TIME)
            GPIO.output([L_STEP, R_STEP], GPIO.LOW)
            sleep(SLEEP_TIME)
            
            stepMoved += 1
        
        # Comme on est à l'ogine, on peut réinitialiser le compteur de pas à 0
        # Et on recule de X pas pour avoir une petite marge
        reculed = moveX(STEP_RETURN, "cw")
        stepMoved -= reculed  # On decremente les pas fait dans l'autre sens, une fois le bout atteint

    except Exception as e:
        print(f"An error occurred: {e}")
    finally:
        return stepMoved

def moveY(step, direction):
    """
    Function to move in Y axis (UP/DOWN), with step and direction

    Parameters:
    step (int): Number of steps to move.
    direction (str): Direction to move ("cw" for clockwise, "ccw" for counter-clockwise).

    Raises:
    ValueError: If step is not a non-negative integer or direction is not "cw" or "ccw".

    Example of use:
    moveY(400, "cw") or "ccw"
    """
    
    if not isinstance(step, int) or step < 0:
        raise ValueError("Step must be a non-negative integer.")
    if direction not in ["cw", "ccw"]:
        raise ValueError('Direction must be "cw" or "ccw".')
    
    stepMoved = 0

    try:
        dir_state = GPIO.HIGH if direction == "cw" else GPIO.LOW
        GPIO.output(R_DIR, not dir_state)
        GPIO.output(L_DIR, dir_state)

        for _ in range(step):
            GPIO.output([L_STEP, R_STEP], GPIO.HIGH)
            sleep(SLEEP_TIME)
            GPIO.output([L_STEP, R_STEP], GPIO.LOW)
            sleep(SLEEP_TIME)
            stepMoved += 1

            if GPIO.input(SWITCH_2) == 0 and direction == "cw":
                print("Limite de course atteinte en Y (origine)")
                reculed = moveY(STEP_RETURN, "ccw")
                stepMoved -= reculed  # On decremente les pas fait dans l'autre sens, une fois le bout atteint
                break
            elif GPIO.input(SWITCH_4) == 0 and direction == "ccw":
                print("Limite de course atteinte en Y (fin)")
                reculed = moveY(STEP_RETURN, "cw")
                stepMoved -= reculed  # On decremente les pas fait dans l'autre sens, une fois le bout atteint
                break
        
        sleep(0.1)

    except Exception as e:
        print(f"An error occurred: {e}")
    finally:
        return stepMoved

def moveYToOrigin():
    """
    Function to move in Y axe to the origin of the rail
    """
    try:
        GPIO.output(R_DIR, GPIO.LOW)
        GPIO.output(L_DIR, GPIO.HIGH)
        print("Déplacement à l'origine en Y")
        
        while GPIO.input(SWITCH_2):	
            
            GPIO.output([L_STEP, R_STEP], GPIO.HIGH)
            sleep(SLEEP_TIME)
            GPIO.output([L_STEP, R_STEP], GPIO.LOW)
            sleep(SLEEP_TIME)

        # Comme on est à l'ogine, on peut réinitialiser le compteur de pas à 0
        # Et on monte de X pas pour avoir une petite marge
        moveY(STEP_RETURN, "ccw")
        print("Arrivé à l'origine en Y")
        

    except Exception as e:
        print(f"An error occurred: {e}")
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

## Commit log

2023-07-31 Ajout de données
2023-08-02 Ecran de chargement OK; CSS images; Barre de defilement sur la gauche;
2023-08-05 Ajout de données/images; Animation play/pause/stop; Animation de fond une fois lancé; CSS;
2023-08-22 CD reste sur player quand les autres changent de place
2024-02-11 Envoie de photos du front OK;
2024-02-12 App prête pour déploiement
    [NOUVEAU_Projet_Jukebox.xlsx]
2024-02-16 Ajout début modés
    [Assemblage.SLDASM, cd.SLDPRT, plaque.SLDPRT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]
2024-03-14 Ajout modé 3D. Pret pour tester sur udoo
    [Assemblage.SLDASM, NOUVEAU_Projet_Jukebox.xlsx, cd.SLDPRT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]
2024-07-14 create test file for move Y, clean project archi
    [Assemblage - Copie.SLDASM, Assemblage.SLDASM, NOUVEAU_Projet_Jukebox.xlsx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]
2024-07-16 Update 3d models;
    [Assemblage - Copie.SLDASM, Assemblage.SLDASM, NOUVEAU_Projet_Jukebox.xlsx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]
2024-07-17 Add/edit files to controller step motors X and Y, servomotor Z and electro magnet. Starting setup stepmachine. Add model 3d for interruptors
    [Assemblage - Copie.SLDASM, NOUVEAU_Projet_Jukebox.xlsx, cd.SLDPRT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]
2024-07-17 Lien entre machine a état et app OK ! ça c b.
    [NOUVEAU_Projet_Jukebox.xlsx]
2024-07-18 On avance b encore. Mise en place d'attente quand on change de state, depuis flask. COmme ça on attend que la machine a é"tat fait son taff, avant de continuer cote flask. Amélioration du lien entre 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
    [NOUVEAU_Projet_Jukebox.xlsx]
2024-10-30 Save data in inputing data OK. Delete image when delete album OK Add 3d models
    [Assemblage - Copie.SLDASM, Jukebox.xlsx, NOUVEAU_Projet_Jukebox.xlsx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]
2024-10-30 OnDrag/onDrop effects
    [Jukebox.xlsx]
2024-10-31 Dernieres modifs
    [Jukebox.xlsx]
2024-10-31 Add docker file for server portoflio Add config for build raspberry or build server
2025-02-14 Modification visu
    [Assemblage - Copie.SLDASM, Assemblage - Copie.STL, Jukebox.xlsx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]
2025-02-26 grosse refonte du front, mode tel,
    [assemblage_plexi.SLDASM, cadre_plexi.SLDPRT, lien_roulement_plaque_plexi.SLDPRT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]
2025-04-08 feat: redign, add some trucs
    [Assemblage2.SLDASM, lien_roulement_plateau_moteur_avec_accroches.SLDPRT, pinion_2.SLDPRT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]
2025-04-11 feat: mise en place d'une limitation des requ"tes sur serveur, et toast pour afficher les messages
2025-04-11 fix: clean function start and stop
    [jukebox_routes.py]
2025-04-11 fix: rotation cd when hover
    [jukebox_routes.py]
2025-04-11 fix: garde la rotation apres dragNDrop
2025-04-12 fix: ok la on peut drag le premier
2025-04-12 feat: add volume to docker compose raspberry
2025-04-13 fix: bug when start some cd
    [stepmachine.py]
2025-04-14 feat: cdPLayer for smartphone, fix some bugs, add route prev/next backend,
    [jukebox_routes.py]
2025-04-15 feat: ajoput menu parameter, et début dev des fonctionnalitées
2025-04-17 fix: cd shape : square, hover btn settings, add readmes, edit workflow
    [Jukebox.xlsx]
2025-04-17 fix: build public image avec dokcerfile.raspberry
2025-04-25 feat: ajout au build docker rapsberry : linux/arm/v8
2025-04-25 feat: ajout fichier pour passer wifi-ap raspberry
2025-04-25 feat: deplacer dockerfile dans dossier raspberry
2025-04-25 feat: chemin dockerfiel raspberry
2025-04-29 fix: edit VIT_BACK_URL for raspberry build front
2025-05-08 feat: doc. Fix: path api for raspberry
2025-05-09 feat: correction btn afficher liste, qui se voyait de partout
2025-05-10 feat: amélioration de la doc
2025-05-11 feat: add build for raspberry with pins
2025-05-11 feat: dockerfile.raspberry
2025-11-25 Feat: modélisations 3D
    [Aimant.SLDPRT, Assemblage2.SLDASM, Assemblage_cd.SLDASM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]
2025-11-25 Fix: edit to 4 emplacments, add infos readme
    [stepmachine.py]
2025-11-25 fix docker raspberry, remove uneusfull architecture
2025-11-25 fix: install RPi.GPIO only for raspberry branch
2025-11-27 feat: add manual move step motors
2025-11-27 fix: add embeded for server
    [config.py]
2025-11-27 fix docker build for raspberry
2025-11-27 fix: add rpi to requirements, add arm/v8 for docker-pûblish
2025-11-27 feat: add fonction for servo and magnet
2025-11-27 fix: import of config
    [moveservomotor.py]
2025-12-09 feat: déplacements mecaniques manuellement OK. Mais pb lecteur, pas fonctionnel pour l'instant
    [Jukebox.xlsx]
2026-07-06 edit projet file
    [Jukebox.xlsx]
2026-08-06 UPDATE suivi projet
    [Jukebox.xlsx]
2026-08-08 UPDATE : detecter les fins de courses, et bloquer le mouvement des moteurs + recul 5 pas
    [Jukebox.xlsx]
2026-08-09 UPDATE : menu calibrage manuel : affichage coordonnées save + btn save quand chariot bon emplacement
    [Jukebox.xlsx]
2026-08-09 BUg, mise en place lecteur jaut droite
    [manual_routes.py, stepmachine.py]
2026-08-09 UPDATE machine a etat go to orinige/end/pos
    [Jukebox.xlsx]
2026-08-09 Normalement enresitrement des step fonctionne tjrs , sans erreur
2026-08-09 FIX : commptage des step oubli dans manual_routes
    [manual_routes.py]
2026-08-09 Remove data in response
    [Jukebox.xlsx]
2026-08-09 MAJ : enleve animation flou de changement dans finally
    [Jukebox.xlsx]
2026-08-15 Bordezu + bonne gestion lecteur, dispay... OK
    [Jukebox.xlsx]
2026-08-15 FIX : différence de pas pour prednre une direction : soustraction pas bonne
    [stepmachine.py]
2026-08-21 Calibrage Z OK ? + Step machine récupère CD, aiamnt, déplace...+ Ajout gestion fhciier data et positions : si pas de fichier on créé un nouveau, sinon on prend elui actuel
    [Jukebox.xlsx]
2026-08-22 Fix: les pas retour sur un bord sont décrémenters
    [Jukebox.xlsx]
2026-08-22 edit manual routes for publi server test, block if not on raspberry
2026-08-25 Add goToOriin in seetin + sleep
    [Jukebox.xlsx]
2026-08-26 Plus bug change cd quand player true; Petits details de visu/fonctionnement
    [Jukebox.xlsx]
2026-08-27 Add logs
    [Jukebox.xlsx]
2026-08-31 Petites modif : timer avant moveZ, si nb pas oriring Z existe on le mprend, sinon on met 0
2026-09-03 Ajout lo déplaement Z
    [Jukebox.xlsx]
